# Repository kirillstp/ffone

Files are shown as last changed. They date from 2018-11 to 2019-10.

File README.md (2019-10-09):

ffone is 6V battery powered RC car controlled via Android application over bluetooth. Car consists of two 6V 30k RPM geared motors with encoders, HC05 bluetooth reciever, Arduino Nano and servo for steering. Power is provided using two 18650 batteries with voltage regulation for microcontroller. Can go up to 25km/h on smooth surface. Chassis is fully 3D printed.

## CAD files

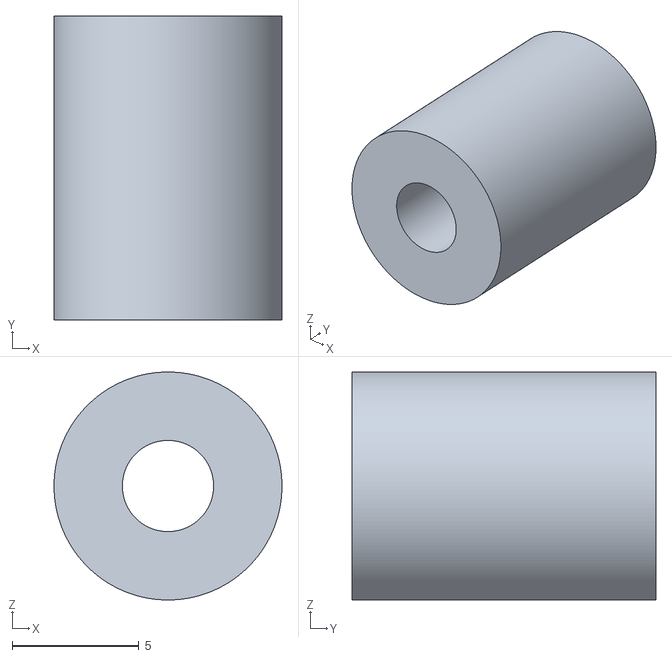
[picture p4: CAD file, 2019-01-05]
drawings/front assembly/front assembly column 1.stl
9.00 x 12.0 x 9.00

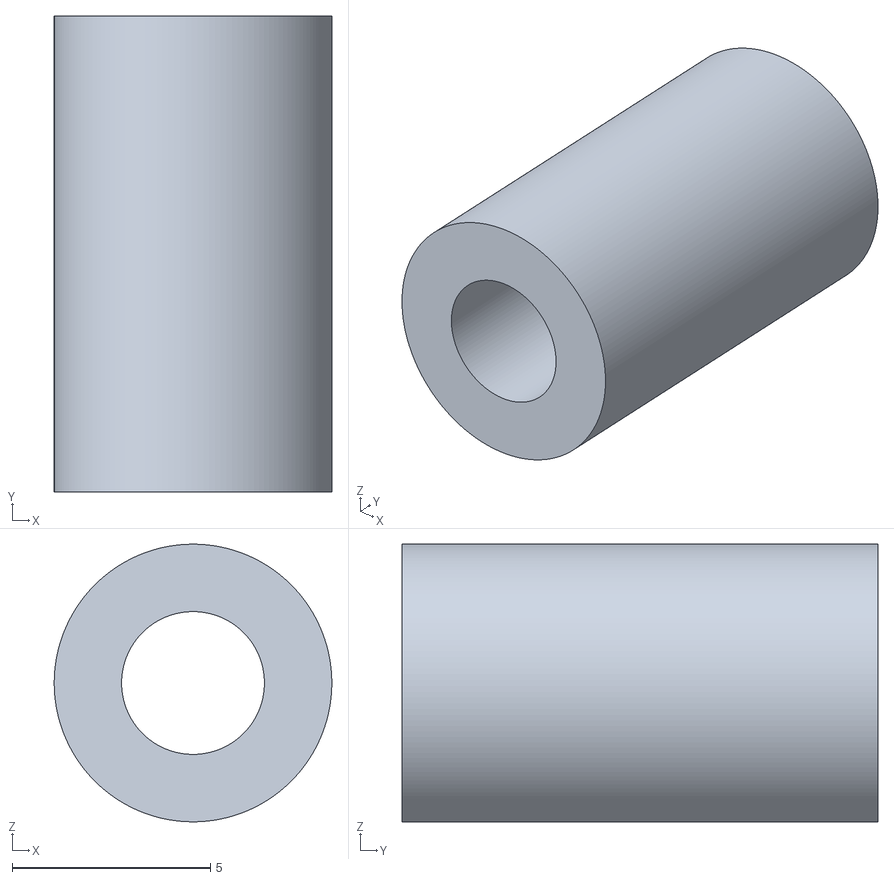
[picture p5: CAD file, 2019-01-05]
drawings/front assembly/front assembly column 3.stl
7.00 x 12.0 x 7.00

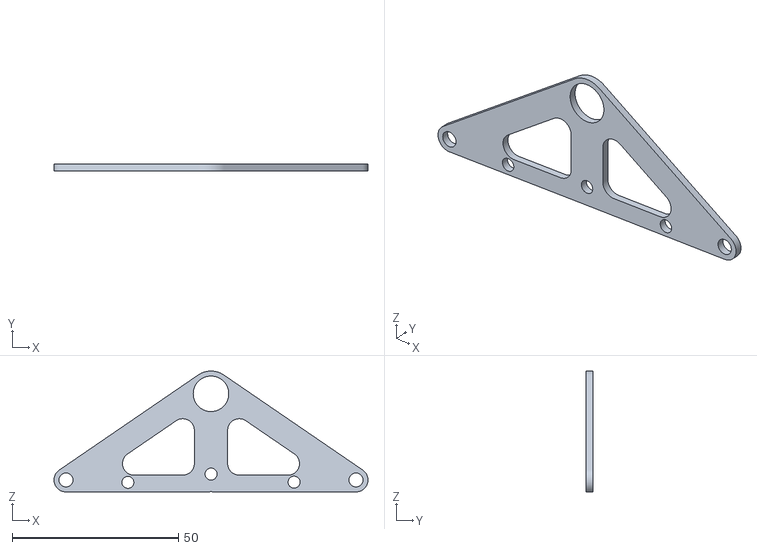
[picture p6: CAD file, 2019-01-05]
drawings/front assembly/front assembly bottom.stl
94.4 x 2.00 x 36.3

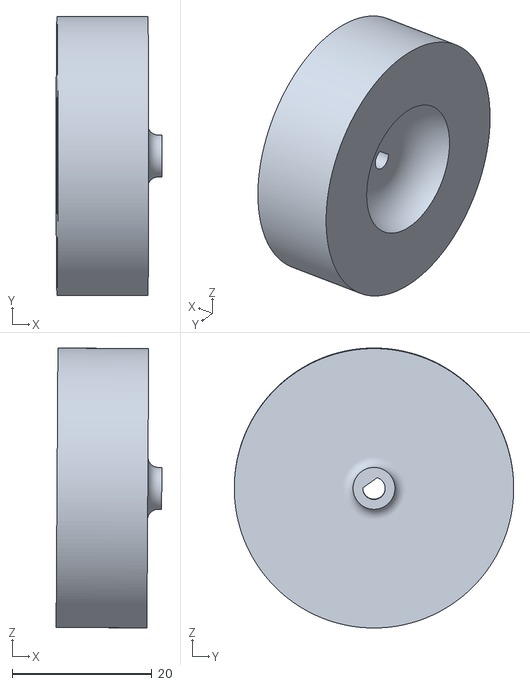
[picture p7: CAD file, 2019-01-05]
drawings/front assembly/back wheel.stl
15.1 x 40.0 x 40.1

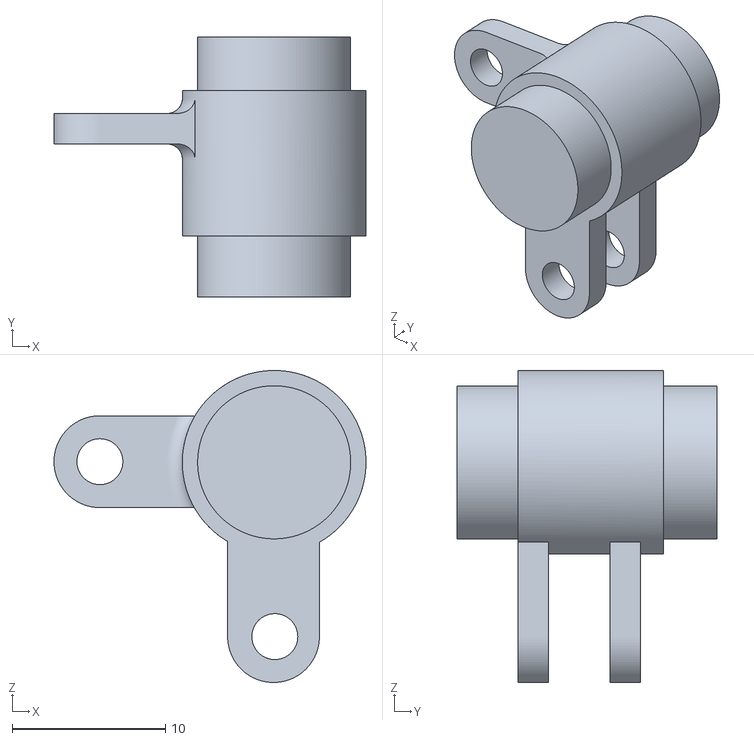
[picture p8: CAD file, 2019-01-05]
drawings/front assembly/twisto.stl
20.4 x 17.0 x 20.4

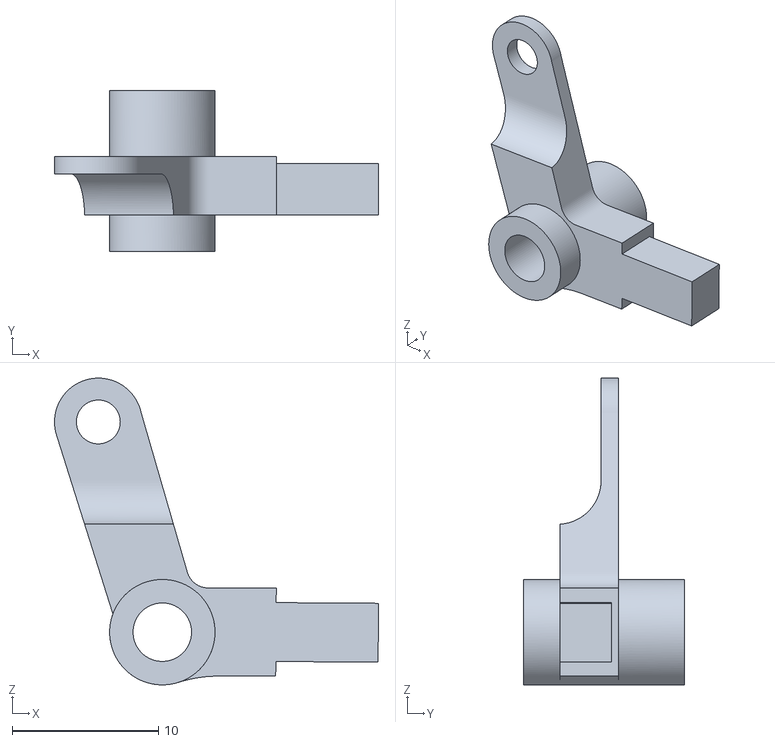
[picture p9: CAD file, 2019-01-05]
drawings/front assembly/R steering linkage.stl
22.2 x 11.0 x 21.0

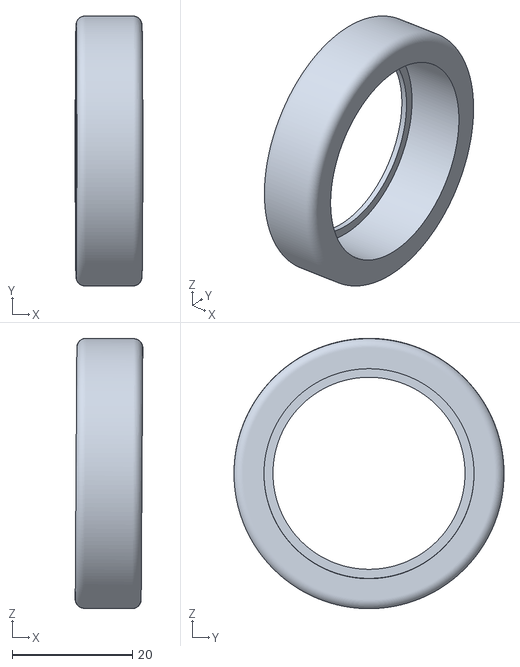
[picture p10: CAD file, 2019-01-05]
drawings/front assembly/front tire.stl
11.3 x 45.0 x 45.1

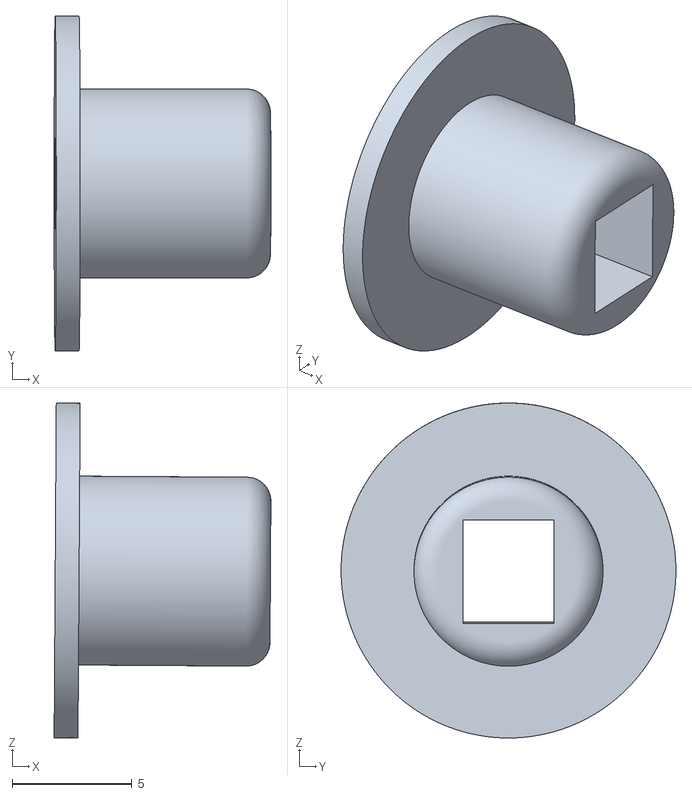
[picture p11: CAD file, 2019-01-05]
drawings/front assembly/wheel hub.stl
9.06 x 14.0 x 14.0

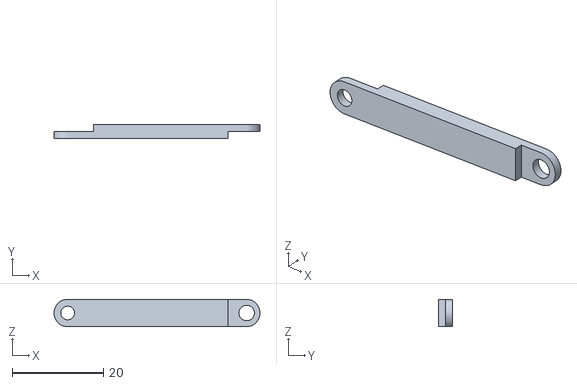
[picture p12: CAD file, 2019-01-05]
drawings/front assembly/L steering bar.stl
45.2 x 3.00 x 6.00

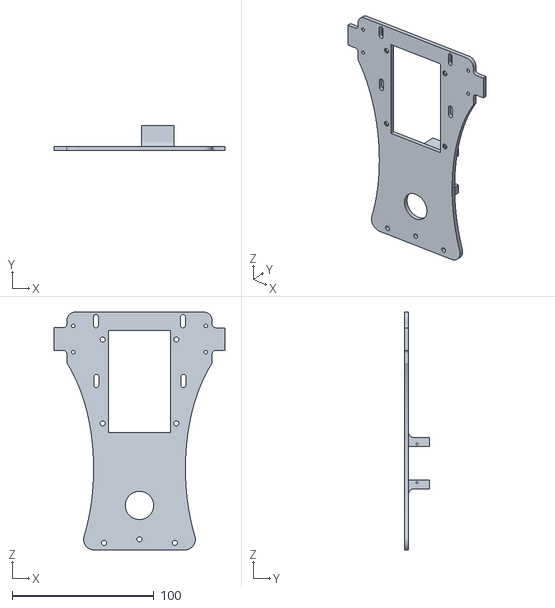
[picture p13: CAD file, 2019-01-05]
drawings/front assembly/floor.stl
120.8 x 17.8 x 168.2

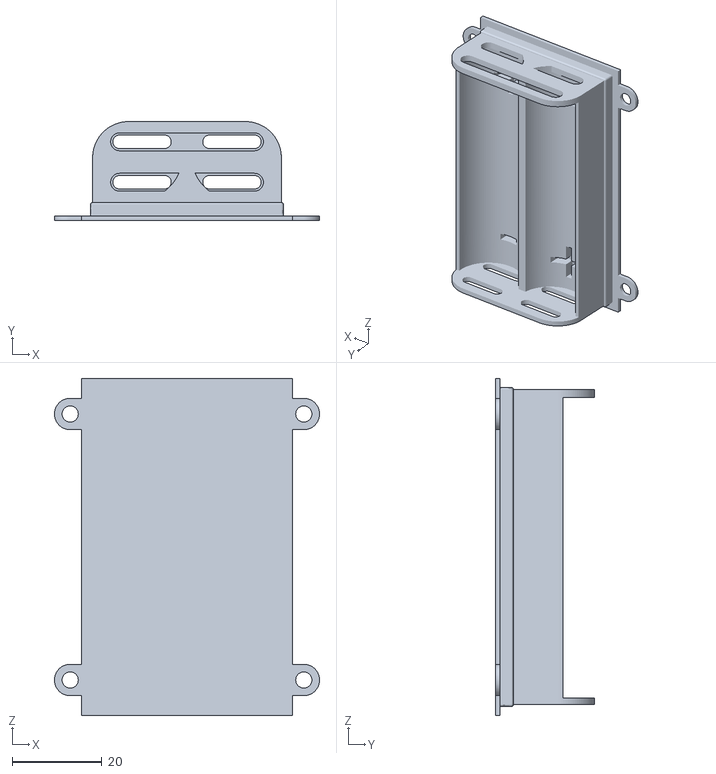
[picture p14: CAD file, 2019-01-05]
drawings/front assembly/battery cover.stl
59.0 x 22.0 x 75.0

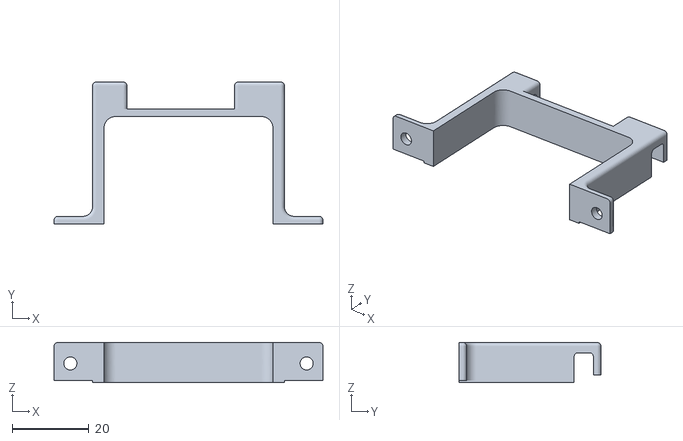
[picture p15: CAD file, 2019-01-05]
drawings/front assembly/back bracket.stl
70.1 x 37.0 x 10.5

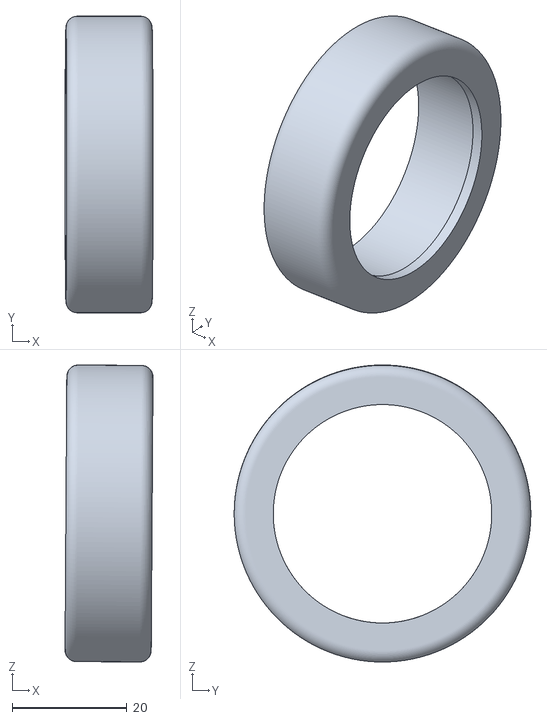
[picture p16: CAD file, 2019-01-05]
drawings/front assembly/back tire.stl
15.3 x 51.6 x 51.7

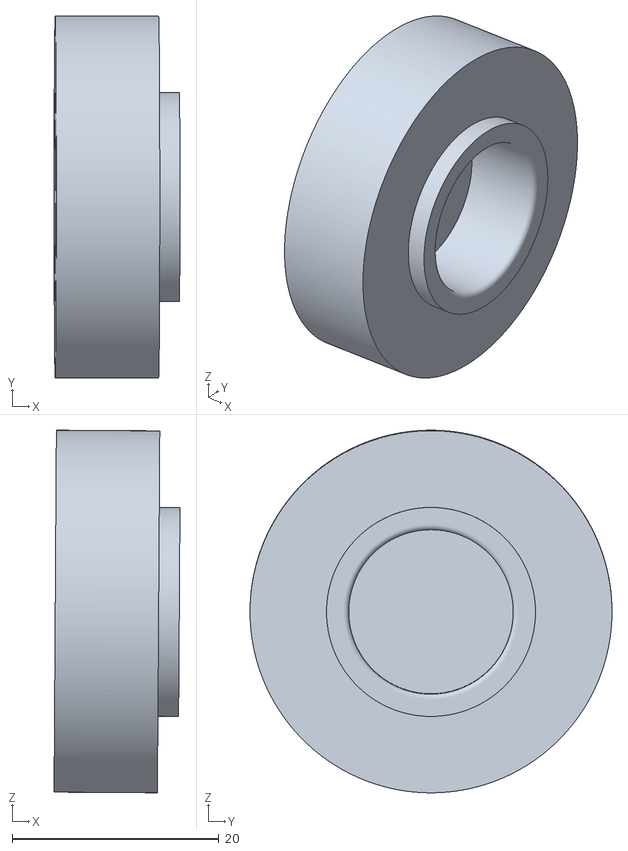
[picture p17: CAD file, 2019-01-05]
drawings/front assembly/front wheel.stl
12.2 x 35.0 x 35.1

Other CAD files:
drawings/front assembly/front assembly column 2.stl
drawings/front assembly/front assembly top.stl
drawings/front assembly/R steering bar.stl
drawings/front assembly/front bracket.stl
drawings/18650_Li-Ion_battery-holderabbb3a716b96de67845202abb42f8cf5-18650_holder_v2_650_2.stl
drawings/18650_Li-Ion_battery-holderd730f603a94162ea31febf235ebd5930-18650_holder_v2_655_wires.stl
drawings/front assembly/L steering linkage.stl

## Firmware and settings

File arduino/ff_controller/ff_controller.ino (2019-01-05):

#include <Arduino.h>
#include <ServoTimer2.h>
#include <AltSoftSerial.h>
#include <ctype.h>

#define R_MOTOR_ENC_PIN 3
#define L_MOTOR_ENC_PIN 2
#define L_MOTOR_DIR_PIN 4
#define L_MOTOR_EN_PIN 5
#define BT_TX_PIN 9
#define BT_RX_PIN 8
#define SERVO_PIN 12
#define R_MOTOR_EN_PIN 6
#define R_MOTOR_DIR_PIN 7
#define VOLT_LED_PIN 13
#define VOLT_PIN 0
#define DEBUG true
#define DEBOUNCE 100 // debounce value in msec
#define MIN_VOLTAGE 6.2
#define STEERING_CENTER 1500
#define STEERING_RANGE 450
#define FOUR_WAY_STEERING true
#define FOUR_WAY_STEERING_LIMIT 0.4
#define STEERING_DEADZONE 0.2

int encoderTicksL = 0;
int encoderTicksR = 0;
float rpm = 0;
float batteryLevel_V = 0;
int steeringAngle = 0;
const byte numRecvData = 32;
char recvData[numRecvData];
boolean newData = false;
const byte numSendData = 32;
char sendData[numSendData];
float turnVal = 0.0;
float accelVal = 0.0;
float boostVal = 0.0;
int moveDirection = 0; // 0 - forward, 1 - backward
unsigned long start;
float fourWaySteering_L = 1.0;
float fourWaySteering_R = 1.0;

AltSoftSerial controllerSerial;
ServoTimer2 steerServo;

void setup() {
  // setup BT
  start = millis();
  if (DEBUG == true){
    Serial.begin(57600);
    Serial.println("Debug serial open...");
  }
  controllerSerial.begin(9600);
  

  // setup motor encoders
  attachInterrupt(digitalPinToInterrupt(R_MOTOR_ENC_PIN), onEncoderTickRight, RISING);
  attachInterrupt(digitalPinToInterrupt(L_MOTOR_ENC_PIN), onEncoderTickLeft, RISING);
  // setup motor pins
  pinMode(L_MOTOR_EN_PIN, OUTPUT);
  pinMode(L_MOTOR_DIR_PIN, OUTPUT);
  pinMode(R_MOTOR_EN_PIN, OUTPUT);
  pinMode(R_MOTOR_DIR_PIN, OUTPUT);
  // setup voltmeter
  pinMode(VOLT_LED_PIN, INPUT);
  digitalWrite(VOLT_LED_PIN,LOW);
  // setup servo
  steerServo.attach(SERVO_PIN);
  steer(map(0, -100, 100, STEERING_CENTER-STEERING_RANGE, STEERING_CENTER+STEERING_RANGE));
  // enable motors
  digitalWrite(L_MOTOR_DIR_PIN, 0);
  digitalWrite(R_MOTOR_DIR_PIN, 0);
}

void loop() {
  // get current time
  // read the serial port
  recvBTSerial();
  fourWaySteering_L = 1.0;
  fourWaySteering_R = 1.0;
  if (newData == true && DEBUG == true) {
        
     if (turnVal < 1.0 && turnVal > -1.0) {
      steer(map(turnVal*100, -100, 100, STEERING_CENTER+STEERING_RANGE,STEERING_CENTER-STEERING_RANGE)); // 2nd arg is 4 wheel steering, changing one side motor speed based on the steering angle.

      if (turnVal <= -STEERING_DEADZONE){
        fourWaySteering_L = max(FOUR_WAY_STEERING_LIMIT, 1.0-abs(FOUR_WAY_STEERING_LIMIT*turnVal));
      }
      else if (turnVal >= STEERING_DEADZONE) {
        fourWaySteering_R =  max(FOUR_WAY_STEERING_LIMIT, 1.0-abs(FOUR_WAY_STEERING_LIMIT*turnVal));
      }
      else{
        turnVal = 0;
      }
    }
    //check the values for their validity
    if (accelVal < 1.0 && accelVal > -1.0) {
      if (accelVal > 0){
        moveDirection = 0;
      }
      else {
        moveDirection = 1;
      }
      accelVal = abs(accelVal);

      if (boostVal > 0.5 && boostVal <= 1.0) {
        accelVal = 254.0;
      }
      else {
        
        accelVal = map(accelVal*100, 0, 100, 0, 200);
      }
      if (FOUR_WAY_STEERING == true) {
        Serial.print("TurnValue ");
        Serial.println(turnVal);
        Serial.print("Left ");
        Serial.println( (int) (fourWaySteering_L*accelVal));
        Serial.print("Right ");
        Serial.println((int) (fourWaySteering_R*accelVal));
        motorLeft((int) (fourWaySteering_L*accelVal), moveDirection);
        motorRight((int) (fourWaySteering_R*accelVal), moveDirection);
      }
      else {
        motorLeft((int) accelVal, moveDirection);
        motorRight((int) accelVal, moveDirection);
      }
    }



    // set movement direction based on the sign of the accelVal (- is forwar
    batteryLevel_V = voltMeter();
    if (batteryLevel_V < MIN_VOLTAGE) {
      digitalWrite(VOLT_LED_PIN,HIGH);
    }
    newData = false;

  }

  float time_diff = millis() - start;

  if (time_diff >= DEBOUNCE) {
    rpm = ((encoderTicksL+encoderTicksR)/8)/(time_diff/60000); 
    start = millis();
    encoderTicksL = 0;
    encoderTicksR = 0;
    controllerSerial.print(rpm);
    controllerSerial.print(',');
    controllerSerial.print(rpm);
    controllerSerial.print(',');
    controllerSerial.print(batteryLevel_V);
    controllerSerial.println('>');
  }
}

void recvBTSerial() {
    static boolean recvInProgress = false;
    static byte ndx = 0;
    char startMarker = '<';
    char endMarker = '>';
    char rc;
    char ctrlr;
    
    while (controllerSerial.available() > 0 && newData == false) {
        rc = controllerSerial.read();
        if (rc == startMarker) {
          recvData[0] = 0;
          ndx = 0;
          recvInProgress = true;
        }
        else if (rc == endMarker) {
          recvInProgress = false;
          recvData[0] = 0;
          ndx = 0;
          newData = true;
        }
        else if (recvInProgress == true) {
          if (rc == 'x' || rc == 'y' || rc == 'b') {
            ctrlr = rc;
          }
          else if (rc == ',') {
            if (ctrlr == 'x'){
              turnVal = atof(recvData);
            }
            else if (ctrlr == 'y'){
              accelVal = atof(recvData);
            }
            else if (ctrlr == 'b') {
              boostVal = atof(recvData);
            }
            recvData[0] = 0;
            ndx = 0;
          }
          else if (isdigit(rc) == true || rc == '.' || rc == '-' ) {
            recvData[ndx] = rc;
            ndx++;
          }
        }
    }
}

void onEncoderTickLeft(int pwmVal){
  encoderTicksL ++;
}

void onEncoderTickRight(int pwmVal){
  encoderTicksR ++;
}

void motorLeft(int val, int dir){
  // set PWM of the left motor
  analogWrite(L_MOTOR_EN_PIN,val);
  digitalWrite(L_MOTOR_DIR_PIN, dir);
}

void motorRight(int val, int dir){
  // set PWM of the  right motor
  analogWrite(R_MOTOR_EN_PIN,val);
  digitalWrite(R_MOTOR_DIR_PIN, dir);

}

void steer(int input) {
  steerServo.write(input);
  delay(15);
}

float voltMeter(){
  float analogValue = 0;
  int i = 0;
  for (i; i < 100; i++){
    analogValue += analogRead(VOLT_PIN);
  }
  analogValue = analogValue/i;
  return ((analogValue*5.0)/(1024.0))*2;
}

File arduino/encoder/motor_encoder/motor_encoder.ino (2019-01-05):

#include <AltSoftSerial.h>
#include <ServoTimer2.h>
#define LH_ENCODER_A 2
#define LH_EN 12
#define LH_PH 11
#define SERVO_PIN 6


int toggle = 0;
int pwmVal = 0;
int shaftSpeed = 0;
int encoderTicks = 0;
AltSoftSerial controllerSerial;
ServoTimer2 steerServo;

void setup() {  
  Serial.begin(9600);
  pinMode(LH_EN, OUTPUT);
  pinMode(LH_PH, OUTPUT);
  pinMode(LH_ENCODER_A, INPUT);
  attachInterrupt(digitalPinToInterrupt(LH_ENCODER_A), onEncoderTick, RISING);
  controllerSerial.begin(9600);
  steerServo.attach(SERVO_PIN);
}

void loop() {
  shaftSpeed = ((encoderTicks/(4))*60)/75; // reading only one out of 4 transitions - 4cpr.  
  encoderTicks = 0;
  Serial.println(shaftSpeed);
  analogWrite(LH_EN,pwmVal);
  digitalWrite(LH_PH,toggle);
  pwmVal += 10;
  pwmVal = pwmVal%200;
  delay(1000);
}

void onEncoderTick() {
  encoderTicks++;
}

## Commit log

2018-11-13 Rough prototype of android app, framework for arduino script and battery enclosure drawings.
    [18650_Li-Ion_battery-holderabbb3a716b96de67845202abb42f8cf5-18650_holder_v2_650_2.stl, 18650_Li-Ion_battery-holderd730f603a94162ea31febf235ebd5930-18650_holder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]
2019-01-05 Working version of ff-one application and arduino code.
    [L steering bar.stl, L steering linkage.stl, R steering bar.stl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]
